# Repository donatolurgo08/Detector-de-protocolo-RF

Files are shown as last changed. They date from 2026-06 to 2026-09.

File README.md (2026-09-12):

# Detector de Protocolo RF 433MHz v1.0

Dispositivo portátil para analizar señales de radiofrecuencia a 433MHz. Permite identificar si un control remoto utiliza **código fijo** (clonable) o **rolling code** (no clonable), mostrando los resultados en pantalla OLED en tiempo real.

<p align="center">
  
</p>

---

## Índice

1. [¿Cómo funciona?](#cómo-funciona)
2. [Uso del dispositivo](#uso-del-dispositivo)
3. [Hardware](#hardware)
4. [Software](#software)
5. [Fabricación](#fabricación)
6. [Roadmap](#roadmap)

---

## ¿Cómo funciona?

El dispositivo escucha señales en la frecuencia de **433.92MHz** a través de un receptor RF. Cuando detecta una transmisión, captura el **código**, el **protocolo** y la **cantidad de bits** de cada paquete recibido.

El proceso requiere **al menos 3 pulsaciones del control a analizar** (con reintento automático hasta 5 si las muestras no coinciden por ruido). Con esas capturas compara si los datos son idénticos entre sí:

- **Código fijo:** al menos 3 paquetes iguales → el control es clonable ✅
- **Rolling code:** los paquetes cambian en cada pulsación → el control no es clonable ❌

Además verifica el **bitrate** de la señal (500–700 baud): si el control trabaja fuera de ese rango muestra `BITRATE NO SOPORTADO` y no lo cuenta como pulsación.

Toda la información se visualiza en la pantalla OLED integrada.

---

## Uso del dispositivo

1. Encendido: Deslizar el interruptor lateral. La pantalla mostrará el logo y luego la pantalla de espera.
2. Apuntar el control remoto al dispositivo y presionar **3 veces** (o mantener).
3. La pantalla irá mostrando cuántas pulsaciones fueron detectadas. Si las muestras no coinciden aparece `No coinciden, repita`: apretar 1–2 veces más.
4. Al completar las capturas, se muestra el resultado:

| Pantalla | Significado |
| --- | --- |
| **COMPATIBLE** | Código fijo — clonable |
| **NO COMPATIBLE** | Rolling code — no clonable |

Ambas pantallas muestran la frecuencia detectada, el protocolo y la cantidad de bits.

5. Reiniciar: Presionar el botón lateral hace que volver a la pantalla de espera. Útil para analizar otro control o si la detección falló.

6. Apagar: deslizar el interruptor lateral a la posición OFF.

**Autoapagado:** si pasan **2 minutos sin actividad** (ningún botón ni señal), el dispositivo entra solo en modo de reposo: la pantalla se apaga y el micro duerme. Apretar el botón lateral lo despierta y lo deja listo en la pantalla de espera.

La batería es recargable — cargala mediante el puerto correspondiente cuando sea necesario.

> ⚠️ La detección depende de la librería RCSwitch, que no cubre todos los protocolos existentes. Algunos controles pueden no ser reconocidos correctamente.

---

## Hardware

### Componentes

Ver lista completa de materiales en [`docs/materiales.txt`](docs/materiales.txt).

### Conexiones

<p align="center">
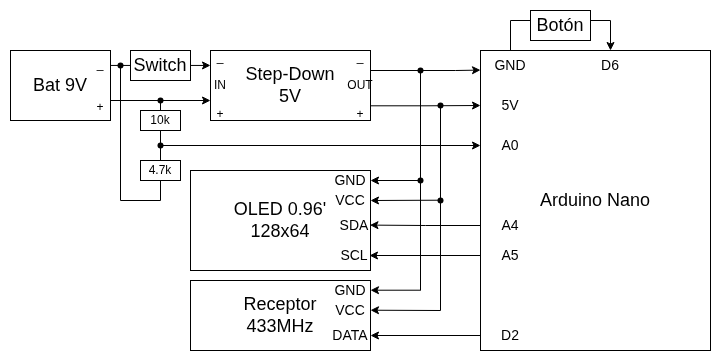
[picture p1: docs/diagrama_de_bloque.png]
  
</p>

---

## Software

[Código](https://github.com/donatolurgo08/Detector-de-protocolo-RF)

### Requisitos

El firmware está escrito en **C++ para Arduino**. Para compilarlo y flashearlo se necesita el **Arduino IDE**.

### Librerías

Instaladas desde el Library Manager del Arduino IDE:

| Librería | Autor |
| --- | --- |
| [RCSwitch](https://github.com/sui77/rc-switch) | sui77 |
| [U8g2lib](https://github.com/olikraus/u8g2) | olikraus |

### Flashear el dispositivo

1. Abrir la capeta `detector_de_protocolo_rf` con Arduino IDE
2. Bajar las librerias con el library manager
3. Seleccioná la placa **Arduino Nano** y puerto COM correspondiente.
4. Hacé clic en **Subir** (→).

---

## Fabricación

El gabinete está impreso en 3D y consta de 3 piezas:

| Pieza | Archivo |
| --- | --- |
| Carcasa principal | `3D/Modelo caja.stl` |
| Tapa | `3D/Tapa.stl` |
| Tope de pantalla  | `3D/Tapa oled.stl` |

---

## Roadmap

Esta es la **versión 1.0** del producto. Las siguientes mejoras están planificadas:

- [x] Autoapagado automático luego de 2 minutos de inactividad (sleep del microcontrolador)
- [x] Mejoras a la carcasa y diseño general
- [x] Soporte para detección de señales a **315MHz**
- [x] Diseño final en PCB dedicada para reducir costos y simplificar el ensamblado

---

_Universal Bi-Tech — Detector de Protocolo RF 433MHz_

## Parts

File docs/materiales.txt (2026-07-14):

- Arduino Nano
- Modulo receptor 433,92MHz
- Pantalla Oled 0,96” 128x64
- Bateria 9V recargable
- Modulo step down
- Switch ON/OF
- Pulsador NA
- Resistencias 10k y 4,7k
- Caja plastica
- PCB perforada

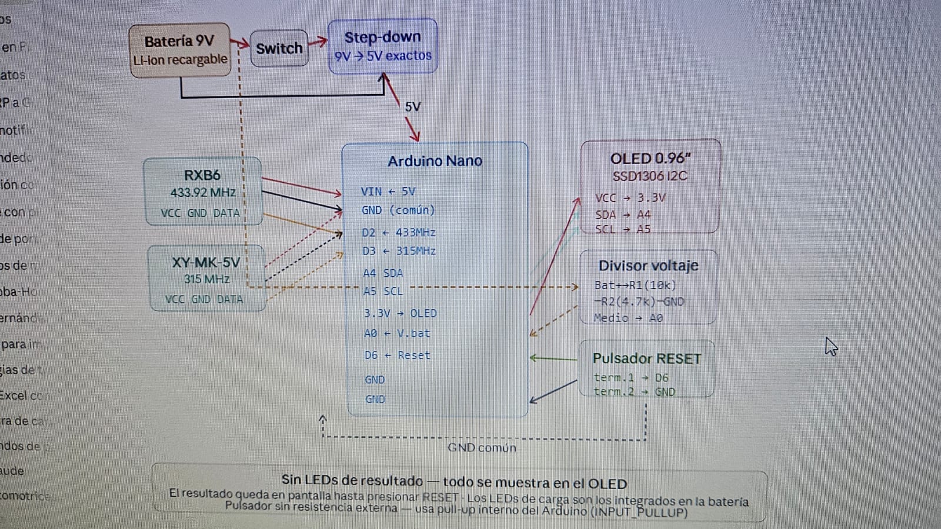
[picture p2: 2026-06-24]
docs/diagrama_componentes_original.jpeg

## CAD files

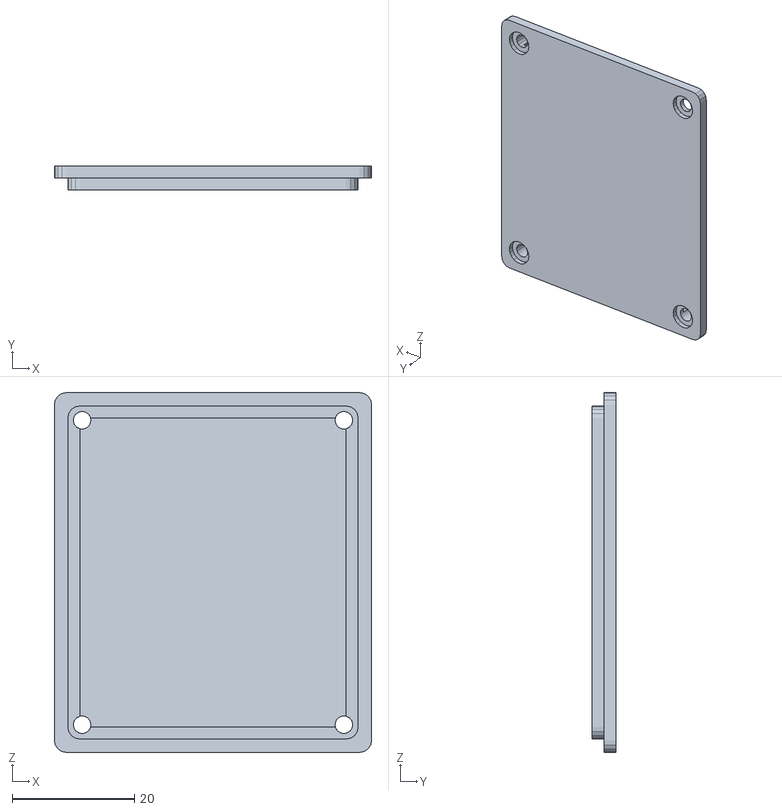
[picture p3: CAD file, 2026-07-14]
3D/Tapa.stl
52.0 x 4.00 x 59.0

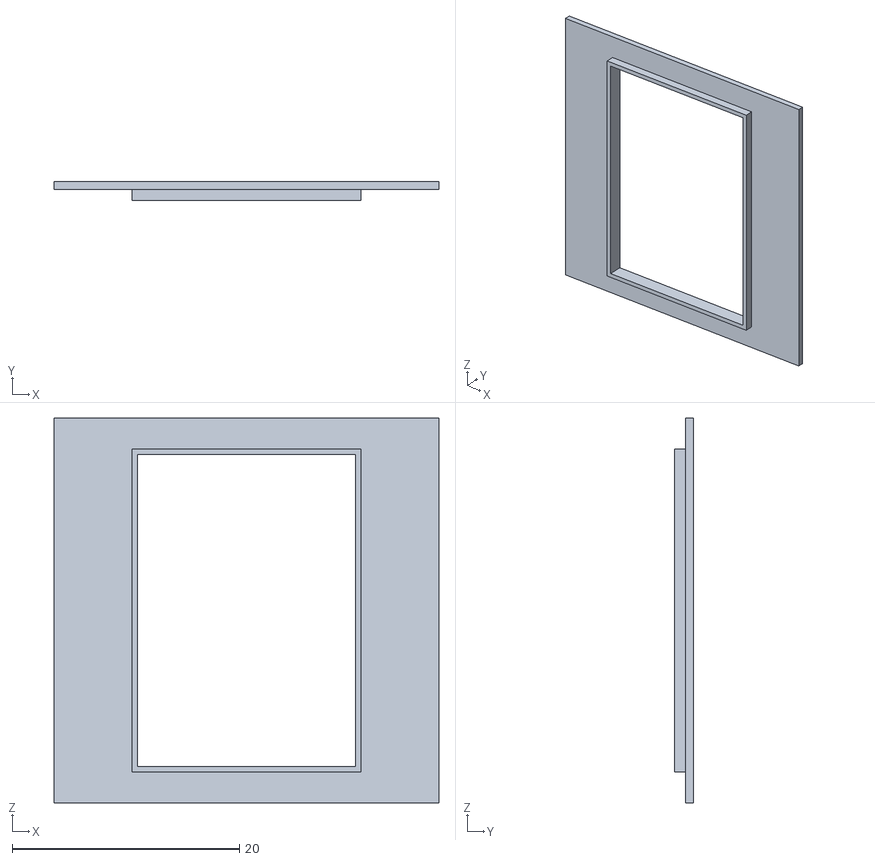
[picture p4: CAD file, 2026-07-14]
3D/Tapa oled.stl
33.9 x 1.70 x 33.9

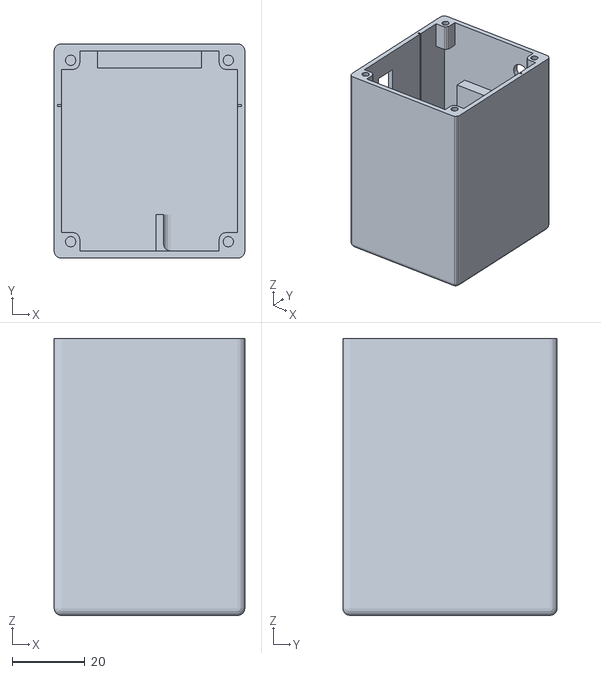
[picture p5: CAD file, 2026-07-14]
3D/Modelo caja.stl
52.5 x 59.0 x 76.2

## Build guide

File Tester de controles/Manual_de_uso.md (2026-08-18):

# Tester de controles — Manual de uso

Simulador de control remoto HT6P20 (protocolo 6 de RCSwitch, 28 bits, invertido)
para ESP32 + módulo TX 433MHz. Sirve para probar el portón y enseñarle códigos
al TXCar sin depender del control real.

## Hardware

- ESP32 DevKit.
- **Datos del módulo transmisor** → **GPIO4** (`PIN_TX`).
- **Boton**: un terminal a **GPIO18** (`PIN_BOTON`) y el otro a **GND**.
- Módulo transmisor a **433MHz**.

## Serial

- Velocidad: **9600 baud**.
- Enviar cada comando seguido de **Enter** (`\n` o `\r`).

## Comandos

| Comando | Descripción |
|---|---|
| `m` | Muestra el menú y el estado actual. |
| `a` … `g` | Selecciona el preset de código (proto 6, 28 bits). |
| `p <us>` | Fija el pulso en microsegundos (default `342`). |
| `r <n>` | Fija las repeticiones por envío (default `10`). |
| `x` | Envía 1 pulsación (n tramas seguidas). |
| `z <s>` | Transmite en continuo durante `<s>` segundos (para enseñar al TXCar). |
| Botón físico | Cada pulsación envía 1 envío (como un control real). |

### Presets

Todos son **protocolo 6, 28 bits, 433MHz**.

| Letra | Código | Pulso | ~bps | Binario | Comentario |
|---|---|---|---|---|---|
| `a` | 51252245 | 342us | ~758 | `0011000011100000110000010101` | Control real que falla en TXCar |
| `b` | 123594517 | 342us | ~758 | `0111010111011110011100010101` | Control real que funciona en TXCar |
| `c` | 58918405 | 342us | ~758 | `0011100000110000011000000101` | Sintético, muchos ceros |
| `d` | 89478485 | 342us | ~758 | `0101010101010101010101010101` | Sintético, alternado puro |
| `e` | 209517045 | 342us | ~758 | `1100011111001111100111110101` | Sintético, muchos unos |
| `f` | 99438357 | **486us** | ~534 | `0101111011010100111100010101` | 534 bps, para probar el portón |
| `g` | 136178533 | **406us** | ~638 | `1000000111011110101101100101` | 638 bps, para probar el portón |

Nota: `f` y `g` fijan también el pulso automáticamente (486us y 406us). Los
presets `a`–`e` usan el pulso actual (default 342us).

## Ejemplos de uso

- Probar el portón con el código de 534 bps:
  ```
  f
  x
  ```
- Enseñarle ese código al TXCar:
  ```
  f
  z 5
  ```
- Ver el estado actual:
  ```
  m
  ```

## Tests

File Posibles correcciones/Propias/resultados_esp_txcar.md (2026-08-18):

# Resultados: caso 51252245 (TXCar)

Prueba realizada para aislar por qué el TXCar no reproducía el control `51252245`
(clonado desde el control real) de modo que abriera el portón.

## Contexto

- Control real `51252245` (HT6P2002): el portón abre con él.
- Clonado en TXCar desde el **control real**: el TXCar NO abre el portón.
- Re-enseñado en TXCar desde el **ESP32 (señal limpia)**: patrón correcto.

## Resultados medidos (ráfagas con el detector)

| Métrica | TXCar (aprendió del control REAL) | TXCar (aprendió del ESP32) | TXCar que FUNCIONA (123594517) |
|---|---|---|---|
| tramas_total | 5 | **7** | 7 |
| Gaps | 113–114ms con **hueco de 228ms** | **111–112ms uniformes** | 112–114ms uniformes |
| sync_high | 400–500 (inestable) | **448–476 (estable)** | 476–504 |
| cero_a / cero_b | 565–597 / 979–1009 | 531–576 / 959–1001 | 527–557 / 1008–1040 |
| uno_a / uno_b | 1043–1108 / 449–508 | 1048–1092 / 440–486 | 1039–1074 / 482–516 |
| Código | 51252245 | 51252245 | 123594517 |

## Conclusión (cuál es el problema)

El problema **no es el código `51252245` ni el TXCar**: es el **proceso de
aprendizaje del TXCar cuando se le enseña desde el control real**.

El TXCar copia mal la señal RF del control original (HT6P2002), generando una
copia "sucia": pocas tramas (5), un hueco doble de 228ms entre tramas y jitter
de sincronización. Esa copia defectuosa es la que el receptor del portón rechaza.

Al enseñarle desde una señal limpia (ESP32 con RCSwitch), el TXCar reproduce
`51252245` con el mismo patrón que el clon que sí funciona: 7 tramas, gaps
parejos 111–112ms y sincronización estable.

**Solución validada:** enseñarle al TXCar desde la señal limpia
(detector → ESP32 → TXCar), no desde el control real.

## Secuencia exacta del fix

1. **Detector** en modo diagnóstico (`Tester de controles/diagnostico_detector`):
   conectado a una PC (A), monitor serial a 9600.
2. **ESP32** con el simulador (`Tester de controles/control_simulado`):
   conectado a otra PC (B), monitor serial a 9600.
3. En el ESP32: `m` para ver el menú. Elegir el código con `a..g` (presets de
   código) o ajustar pulso/repeticiones con `p <us>` / `r <n>`.
4. Verificar con `x` (1 pulsación) que el detector capta el
   `DIAGNOSTICO RAFAGA` con el código correcto y timings limpios.
5. Poner el TXCar en modo aprendizaje (según su manual).
6. En el ESP32: `z 5` — transmite el código durante 5 segundos apuntando al
   TXCar.
7. Verificar la reproducción del TXCar con el detector: debe dar ≥7 tramas y
   gaps parejos (patrón "limpio").
8. Probar contra el portón.

## Datos de referencia

- `51252245` = protocolo 6 (HT6P20B), 28 bits, pulso 342us → preset `a`.
- Presets del simulador: `a` 51252245, `b` 123594517, `c` 58918405, `d` 89478485,
  `e` 209517045, `f` 99438357 (534 bps), `g` 136178533 (638 bps).

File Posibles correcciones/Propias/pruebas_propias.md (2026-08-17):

# Pruebas propias (con el detector de protocolo RF)

Pruebas orientadas al control que falla (`51252245`, HT6P2002) y su clon en TXCar.

## A. Con el firmware actual (sin tocar código)

1. **Consistencia del clon que falla**: 5–10 pulsaciones del TXCar clonado de `51252245` → ¿siempre ~5 tramas y jitter alto? ¿O cambia según cómo se aprieta?
2. **Mantener apretado 2–3 s** en el TXCar clonado → ver `tramas_total`. Si sube de 5 a 8–10, el control manda más tramas al mantener → el problema es cantidad de repeticiones.
3. **Baseline comparativo**: hacer lo mismo con el clon que sí funciona (`123594517`) → 5 pulsaciones para tener patrón (7 tramas, gaps parejos, timings limpios).
4. **Control remoto con `pruebas/transmitter`**: el ESP32 puede regenerar exactamente el código `51252245` (proto 6, 28 bits) variando `setRepeatTransmit(4/5/7/10)` y el pulso (342 vs 539 us). Esto aísla si el detector pierde tramas por culpa del TXCar o del receptor barato. Comparar qué recibe el detector en cada configuración.

## B. Con firmware extendido

5. **Ventana de 2000 ms** → capturar la pulsación completa sin cortar la cuenta.
6. **Métricas de jitter** en el resumen (min/max/σ de símbolos 0 y 1 + tramas por pulsación) → cuantificar si el clon que falla es "sucio" de forma consistente.
7. **Prueba de re-aprendizaje**: grabar el portón usando el clon TXCar. Si abre → es tema de instalación/aprendizaje, no del clonador.

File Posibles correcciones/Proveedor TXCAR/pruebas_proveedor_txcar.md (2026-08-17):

# Pruebas para el fabricante/distribuidor del TXCar

Pruebas que debería hacer el proveedor del TXCar para determinar si el problema del control `51252245` (HT6P2002) es un error de instalación del producto o un defecto del clonador.

## Diagnóstico técnico de su producto

1. **Medir con SDR / osciloscopio** la señal emitida por el TXCar para `HT6P2002` vs `HT6P20D`:
   - Forma de onda completa (preámbulo, sync, datos, gaps entre tramas).
   - **Cantidad de repeticiones por pulsación** (nosotros medimos 5 vs 7).
   - **Jitter de cada pulso** (nosotros medimos desvíos de hasta ~30 %).
   - Frecuencia exacta (433.92 MHz o deriva).
2. **Comparar lo que el TXCar dice haber guardado vs lo que transmite** → detectar si pierde bits al aprender o al regenerar.
3. **Test de compatibilidad con HT6P2002**: probar el clon contra receptores reales de learning code para ver en cuáles falla y en cuáles no.
4. **Revisar el algoritmo de aprendizaje/reproducción**: si regenera bien `HT6P20D` pero mal `HT6P2002`, es un bug de su software (ambos son familia HT6P20, deberían tratarse igual).

## Cierre de caso (soporte)

5. **Actualización de firmware del TXCar** si es actualizable, con este caso como repro.
6. **Manual/instalación**: documentar qué encoders soporta de forma confiable y si ciertos receptores exigen re-aprender con el clon.

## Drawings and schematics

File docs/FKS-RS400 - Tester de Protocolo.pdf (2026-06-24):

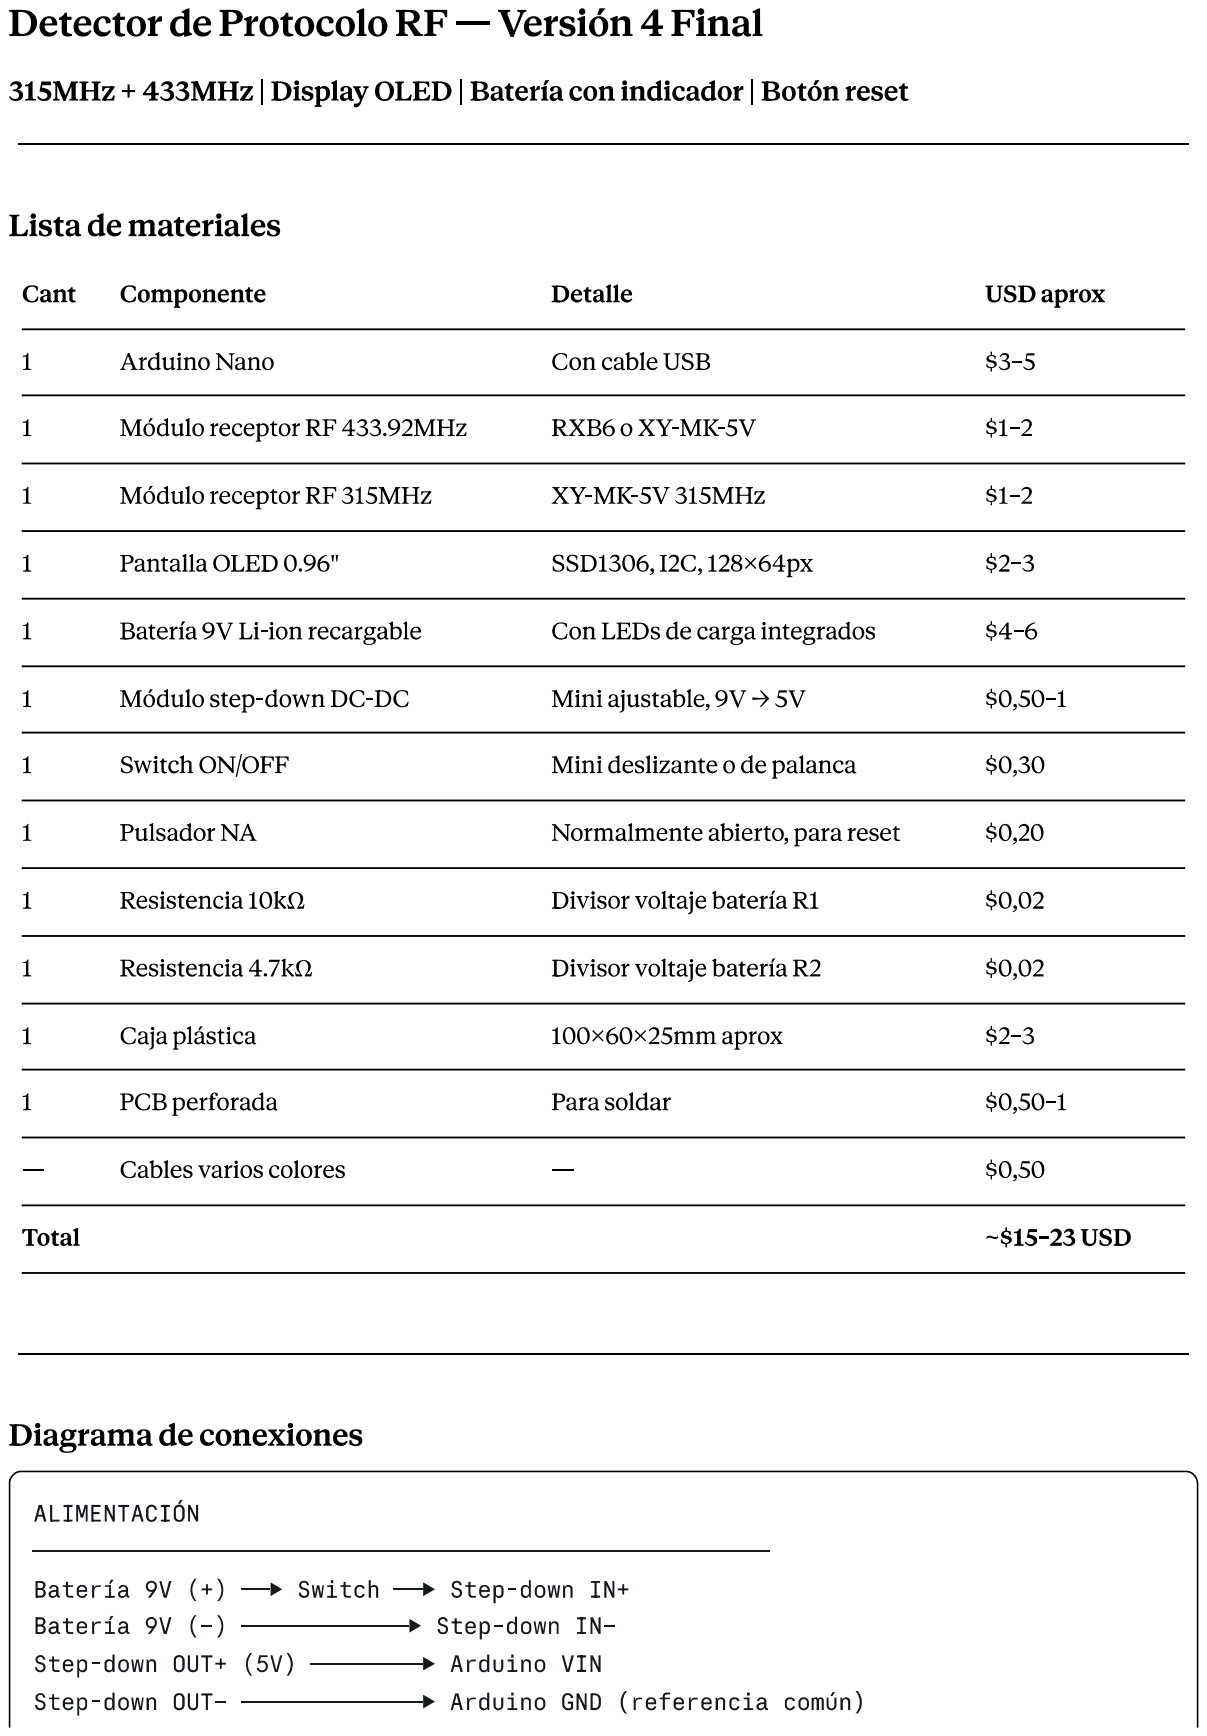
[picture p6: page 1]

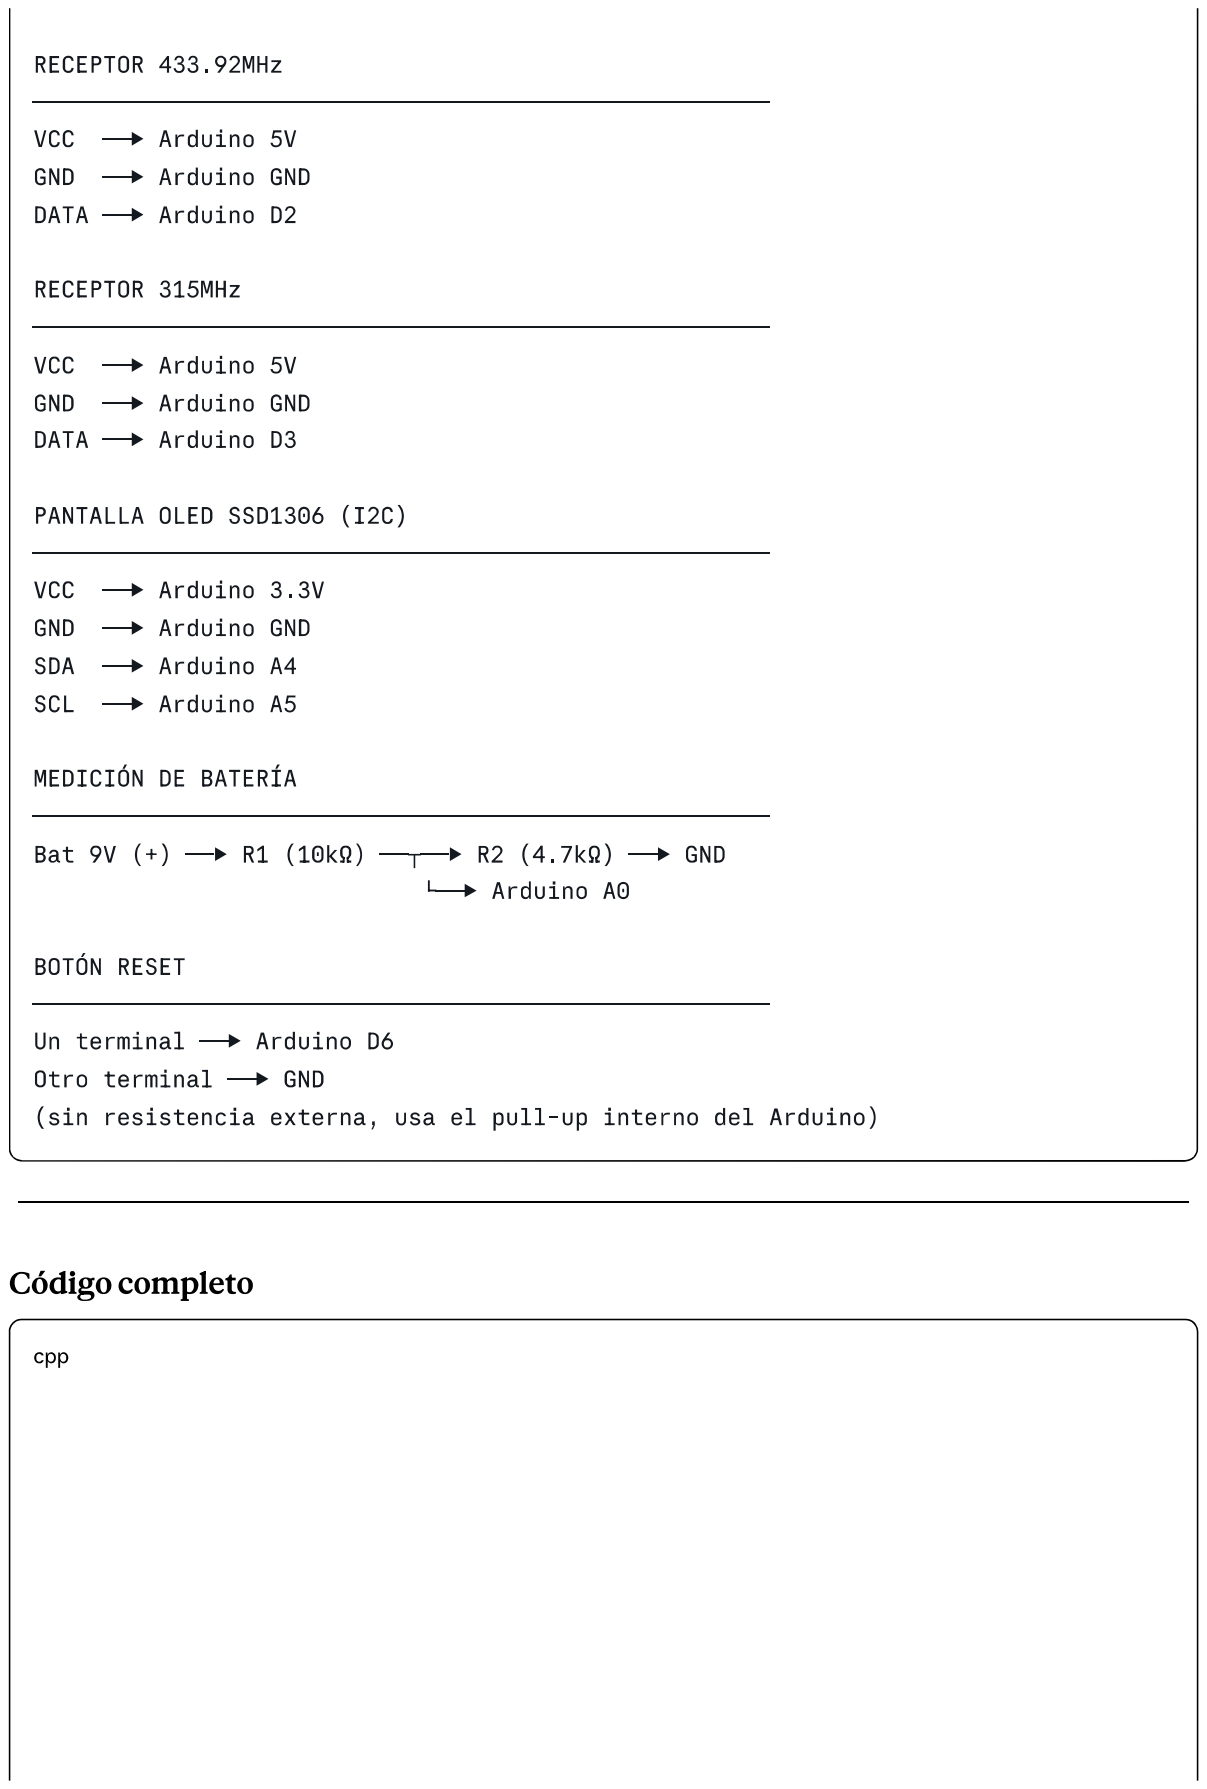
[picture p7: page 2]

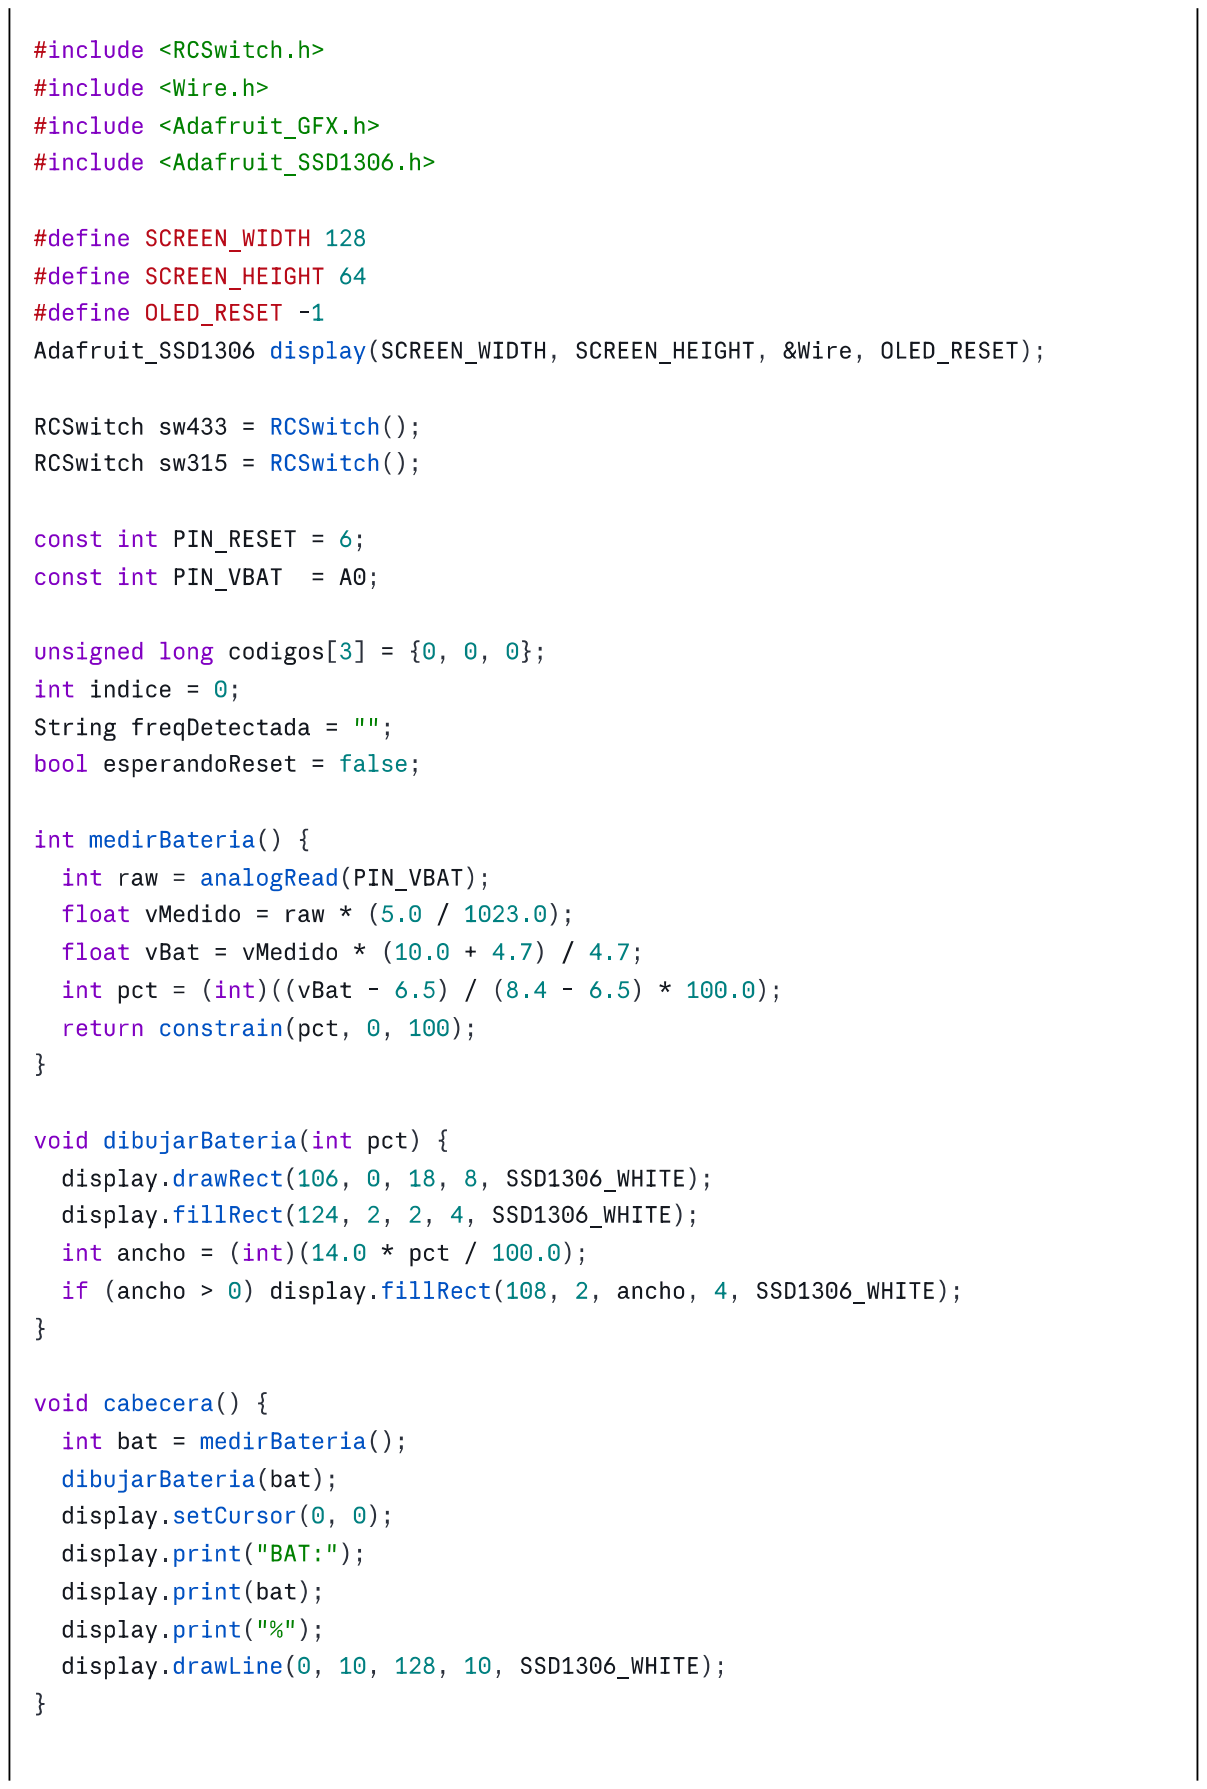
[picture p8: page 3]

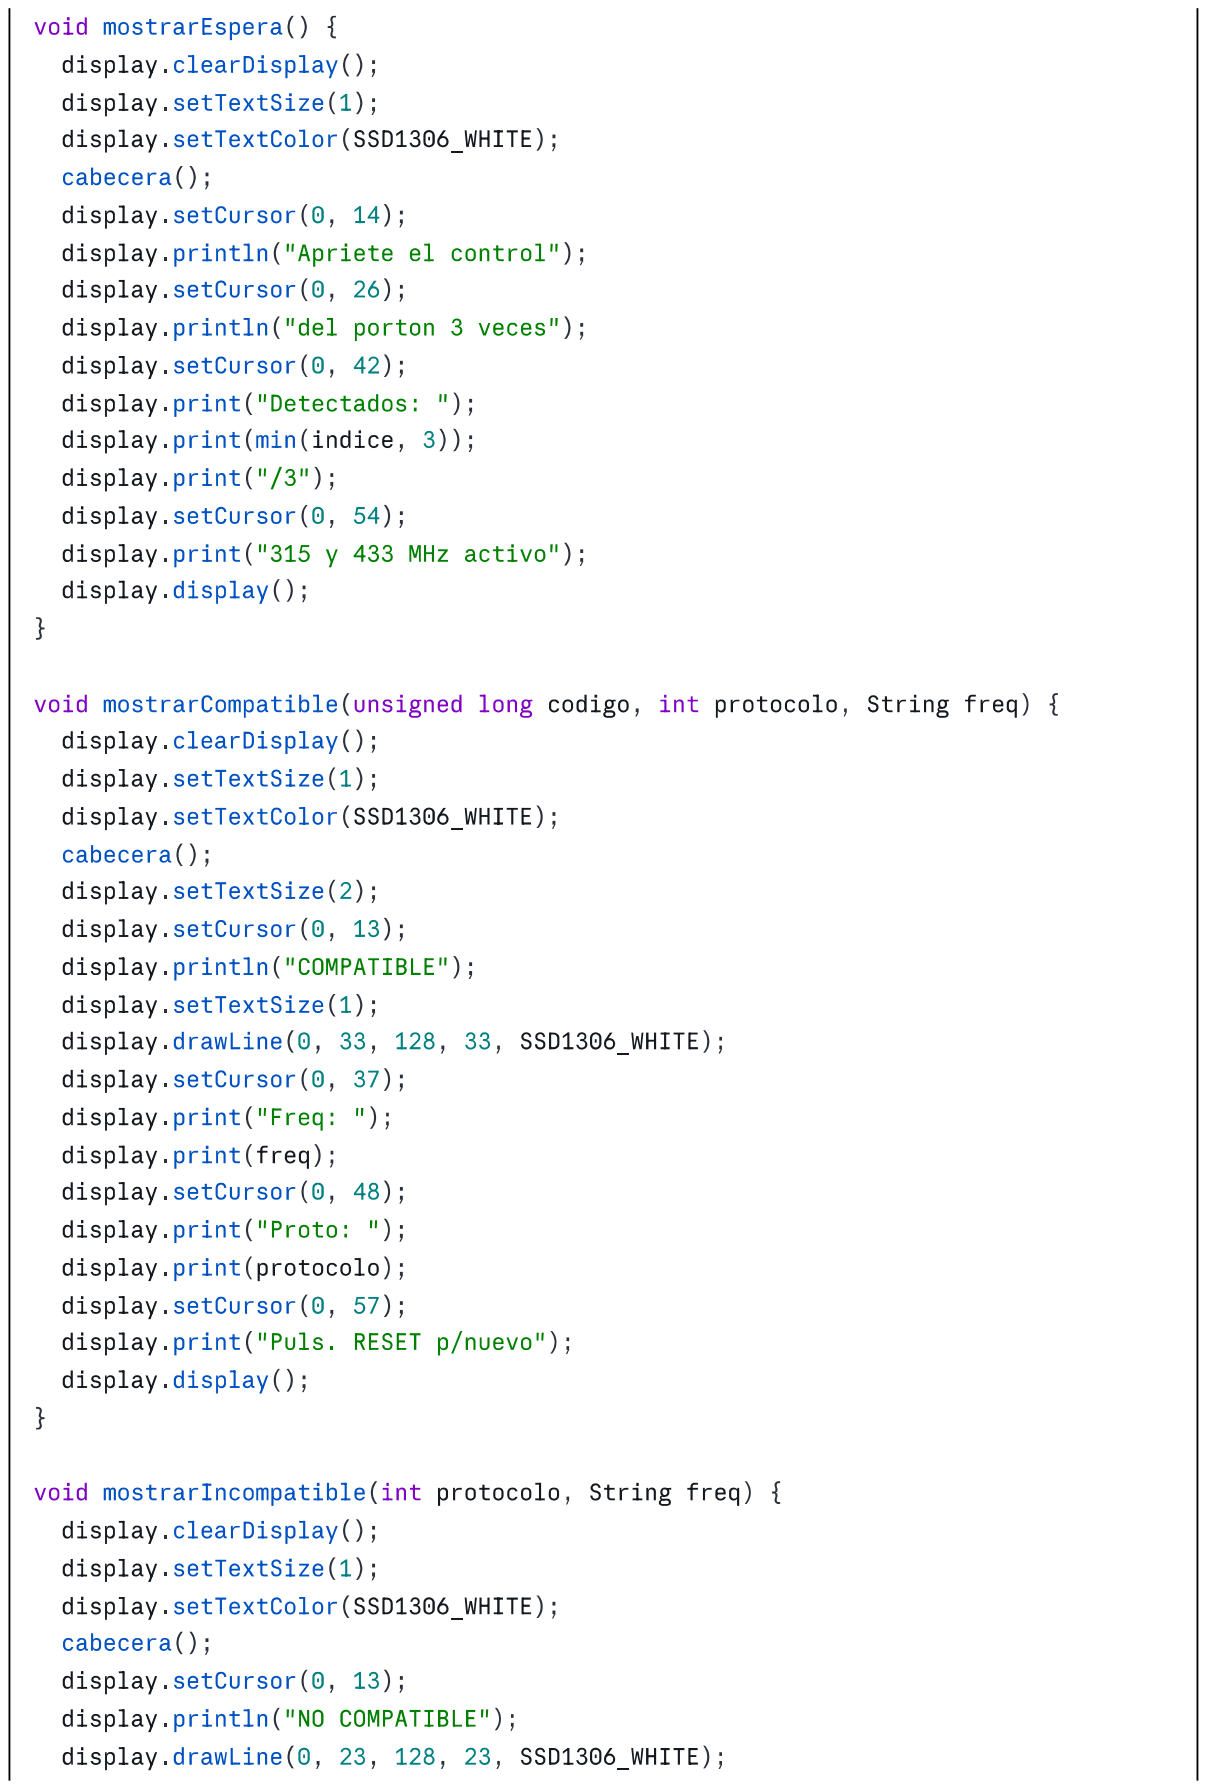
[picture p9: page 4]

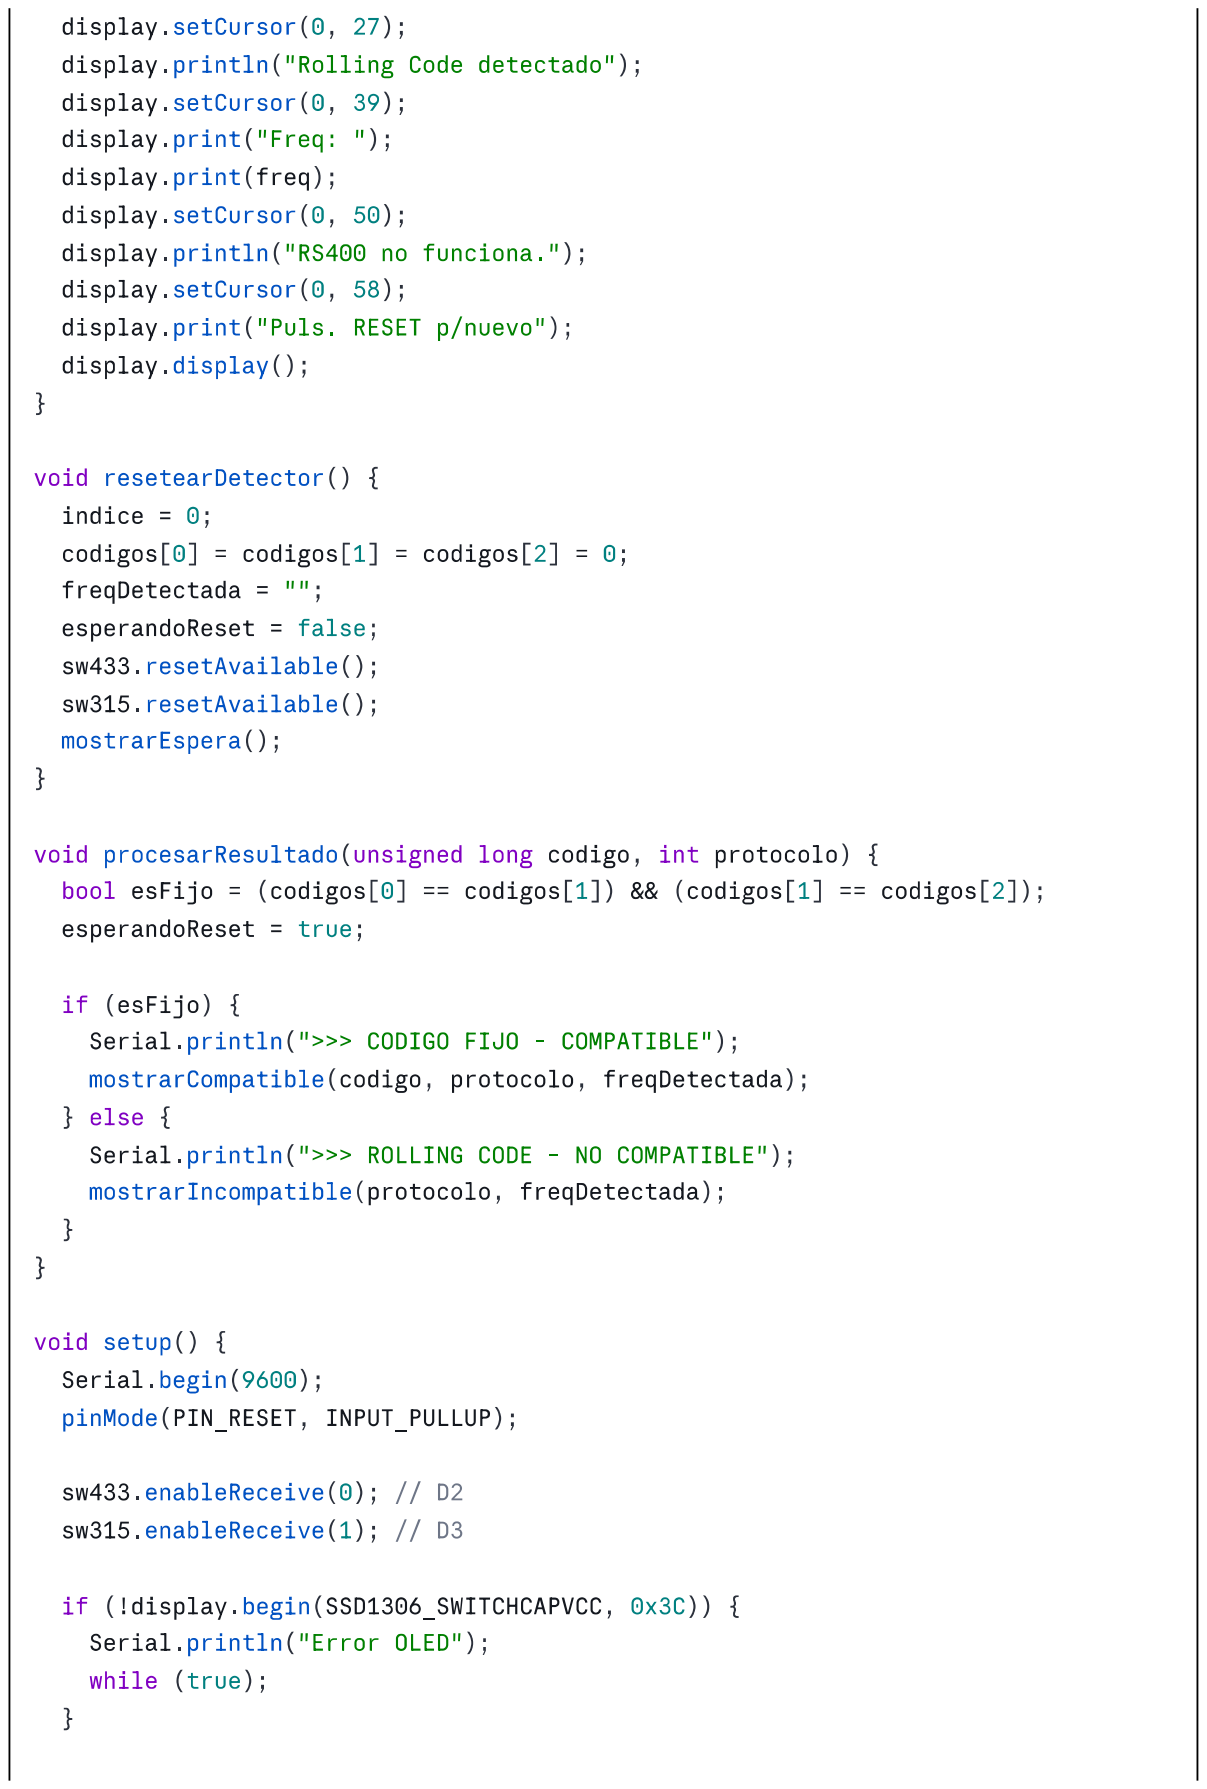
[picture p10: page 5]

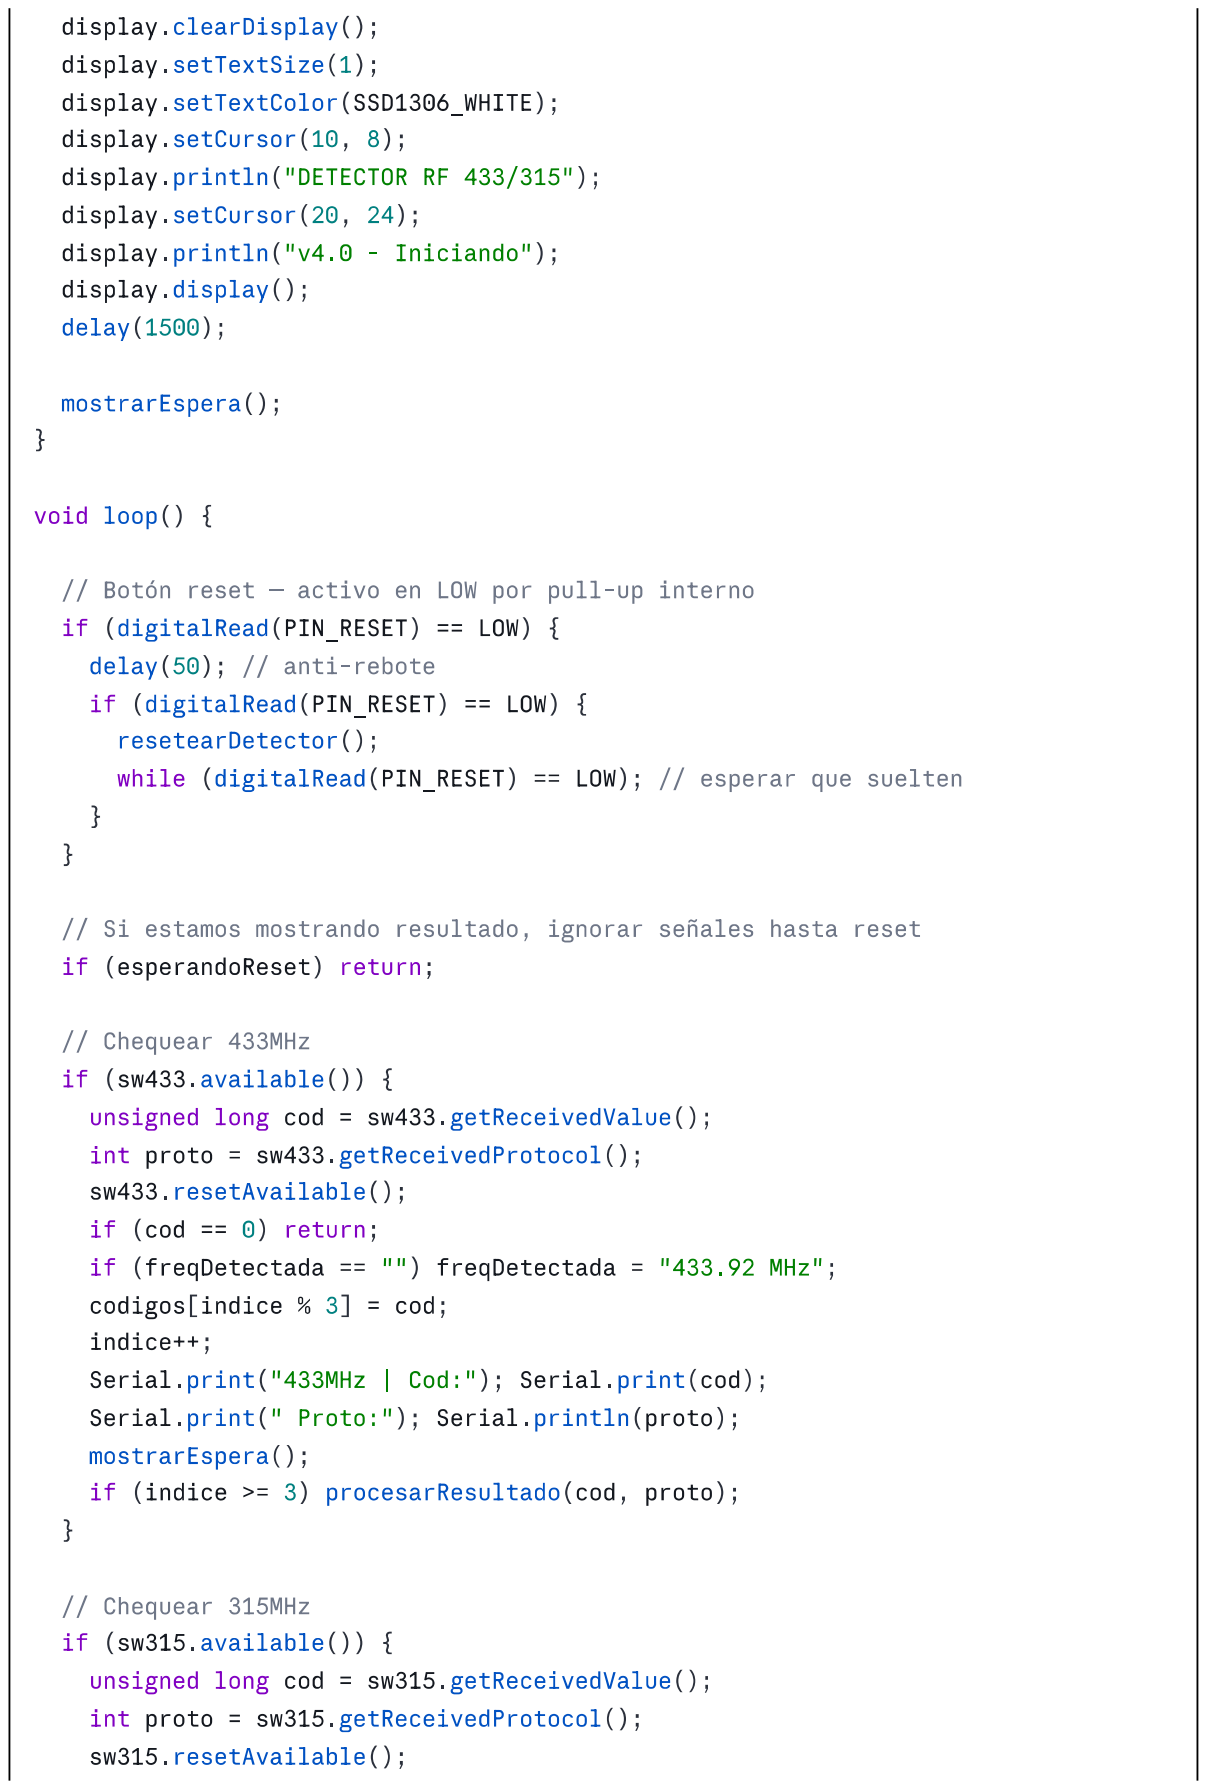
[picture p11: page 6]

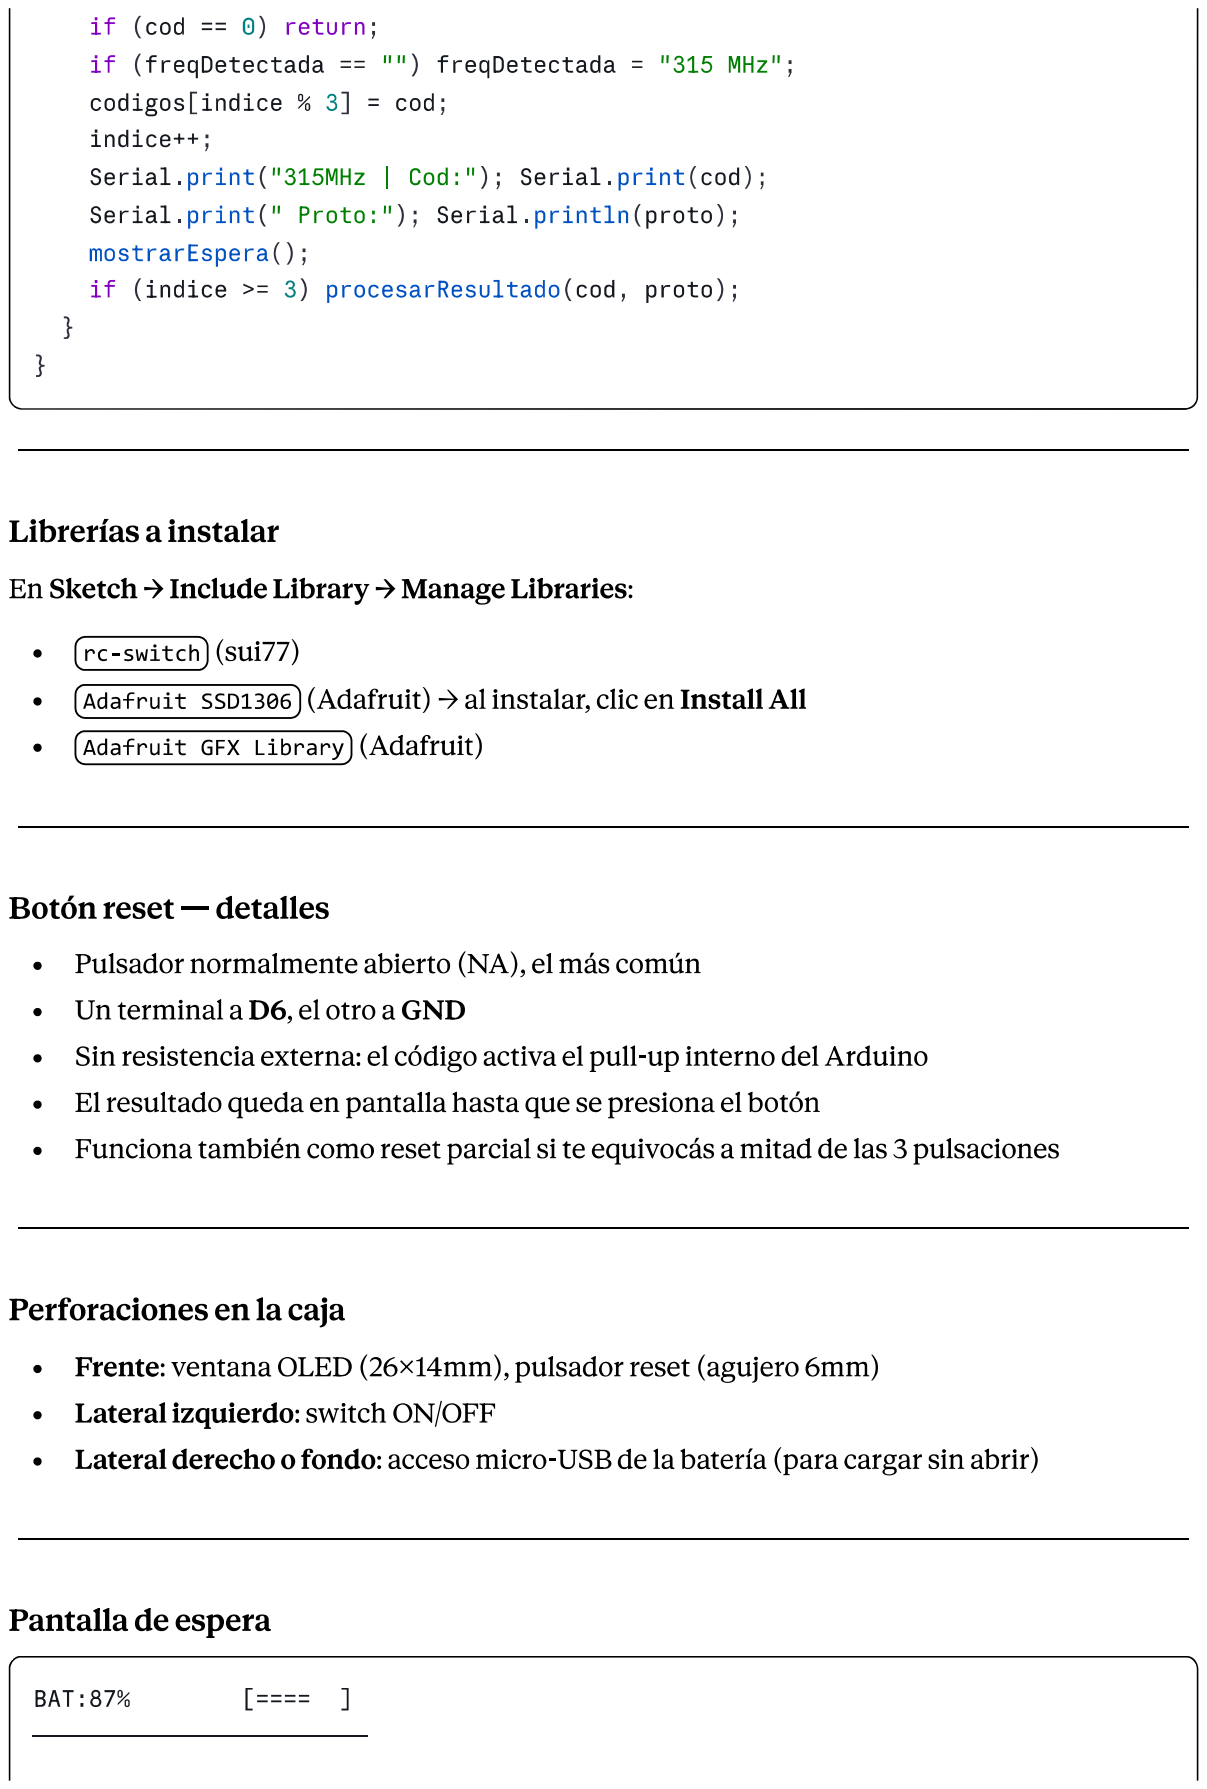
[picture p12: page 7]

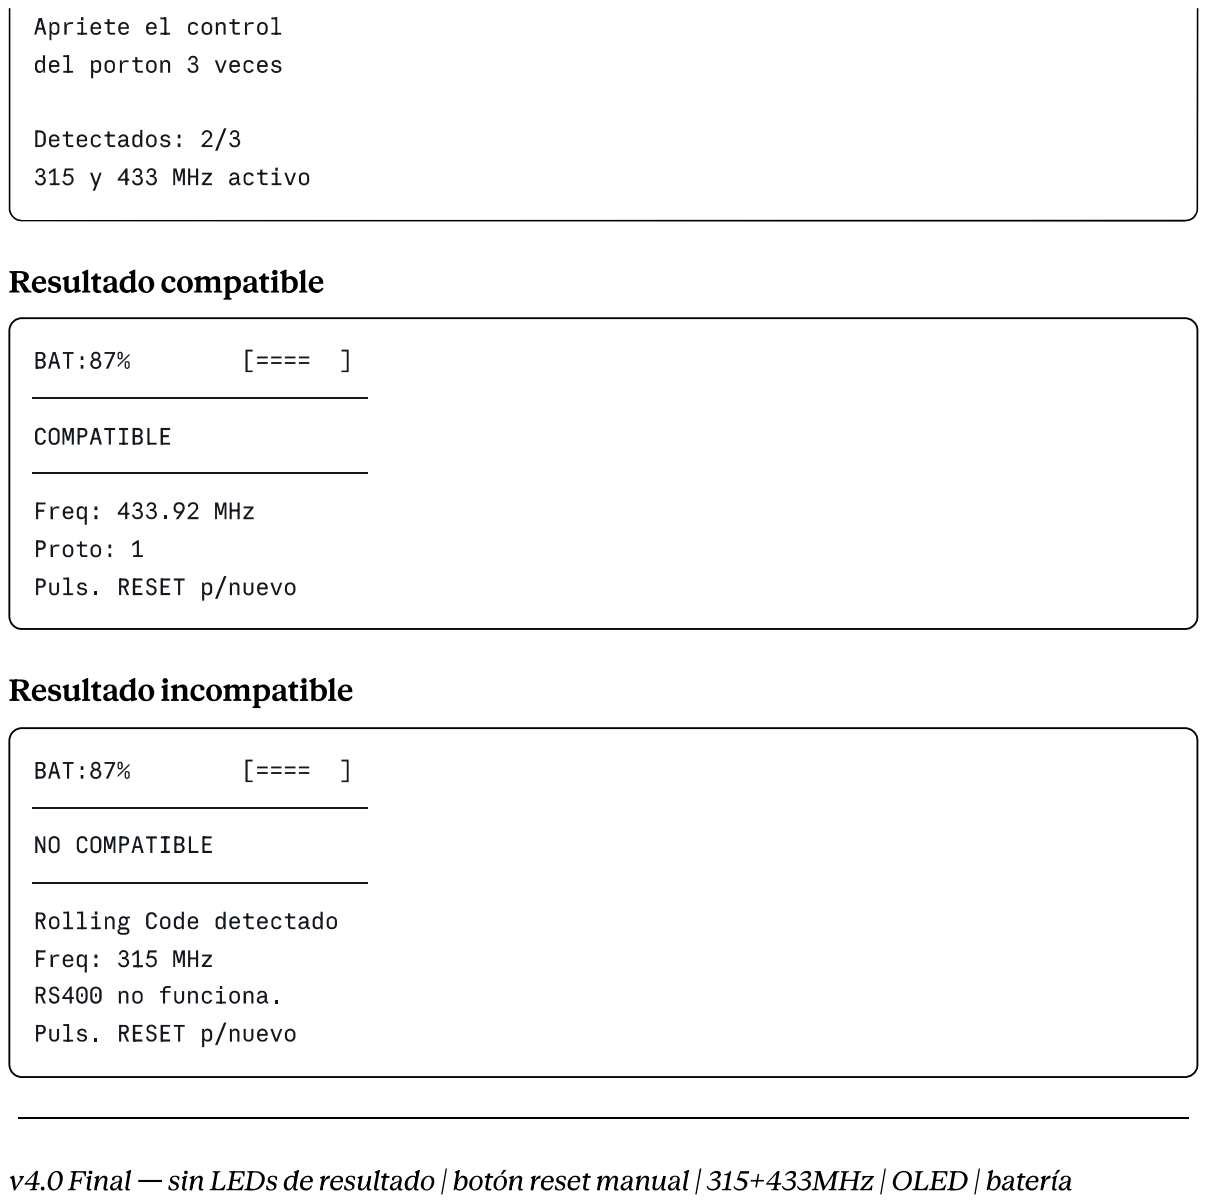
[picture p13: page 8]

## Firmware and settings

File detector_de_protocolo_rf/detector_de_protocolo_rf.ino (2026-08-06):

#include <RCSwitch.h>
#include <U8g2lib.h>
#include <Wire.h>
#include <avr/sleep.h>
#include <avr/wdt.h>
#include "logo_bitech.h"

// U8g2 en modo página de 128 bytes (vs 1024 de Adafruit)
U8G2_SSD1306_128X64_NONAME_2_HW_I2C u8g2(U8G2_R0, U8X8_PIN_NONE);

RCSwitch sw433 = RCSwitch();

const int PIN_RESET = 6;

// ---- Constantes de detección ----
const int MAX_CAPTURAS = 5;     // máximo de capturas antes de decidir
const int MIN_IGUALES = 3;      // mínimo de tramas iguales para dar COMPATIBLE
const int BAUD_MIN = 400;       // ventana de bitrate soportada (baud)
const int BAUD_MAX = 800;
const int RECEIVE_TOLERANCE = 50;  // % de tolerancia de RCSwitch (default 60)
const unsigned long TIMEOUT_SLEEP = 120000UL;  // autoapagado por inactividad (2 min)

// ---- Struct de paquete ----
struct Paquete
{
  unsigned long codigo;
  int protocolo;
  int bits;
  int pulso;
  int baud;
};

Paquete capturas[MAX_CAPTURAS];
int indice = 0;
bool esperandoReset = false;
bool reintentando = false;
unsigned long ultimaActividad = 0;

// -----------------------------------------------------------

// Factores de pulso por protocolo RCSwitch (sync, zero, one), en PROGMEM.
// La duración de la trama se deriva de estos y del pulso medido, sin depender
// del buffer crudo de timings (que el ISR sigue sobrescribiendo).
struct FactoresProto
{
  uint8_t syncH, syncL;
  uint8_t zeroH, zeroL;
  uint8_t oneH, oneL;
};

static const FactoresProto PROGMEM factoresProto[12] = {
  {  1, 31,  1,  3,  3,  1 },   // 1
  {  1, 10,  1,  2,  2,  1 },   // 2
  { 30, 71,  4, 11,  9,  6 },   // 3
  {  1,  6,  1,  3,  3,  1 },   // 4
  {  6, 14,  1,  2,  2,  1 },   // 5
  { 23,  1,  1,  2,  2,  1 },   // 6
  {  2, 62,  1,  6,  6,  1 },   // 7
  {  3,130,  7, 16,  3, 16 },   // 8
  {130,  7, 16,  7, 16,  3 },   // 9
  { 18,  1,  3,  1,  1,  3 },   // 10
  { 36,  1,  1,  2,  2,  1 },   // 11
  { 36,  1,  1,  2,  2,  1 },   // 12
};

// Bitrate (baud) promedio sobre la trama completa (sync + todos los bits).
// Determinístico: se calcula de los valores ya decodificados por RCSwitch
// (pulso, bits, código y protocolo), no del buffer crudo. Así una misma señal
// siempre da la misma baud (el buffer live variaba con el micro-timing de la
// lectura, dando dos bauds distintos para el mismo envío).
// baud = 1e6 * bits / (pulso * (suma de factores de cada bit + sync))
int calcularBaud(unsigned long codigo, int bits, int protocolo, int pulso)
{
  if (bits <= 0 || pulso <= 0 || protocolo < 1 || protocolo > 12)
    return 0;

  FactoresProto f;
  memcpy_P(&f, &factoresProto[protocolo - 1], sizeof(FactoresProto));

  unsigned long sumaFactor = f.syncH + f.syncL;   // el sync forma parte de la trama
  for (int i = bits - 1; i >= 0; i--)
  {
    if (codigo & (1UL << i))
      sumaFactor += f.oneH + f.oneL;
    else
      sumaFactor += f.zeroH + f.zeroL;
  }

  unsigned long sumaUs = (unsigned long)pulso * sumaFactor;
  if (sumaUs == 0)
    return 0;                           // evitar división por cero

  return (int)(1000000UL * bits / sumaUs);
}

// -----------------------------------------------------------

void resetearDetector()
{
  indice = 0;
  esperandoReset = false;
  reintentando = false;
  for (int i = 0; i < MAX_CAPTURAS; i++)
    capturas[i] = {0, 0, 0, 0, 0};
  sw433.resetAvailable();
  mostrarEspera();
}

// Comparación tolerante: tolera un bit de diferencia (glitches del receptor).
// - El pulso (µs) debe ser similar: mismo control => mismo ritmo de transmisión.
// - Bits iguales: el código debe coincidir.
// - Bits difieren en 1: coincide si el código es idéntico (glitch al final en
//   protocolos invertidos) o si coincide al descartar el bit espurio (codigo>>1).
bool mismaTrama(Paquete &a, Paquete &b)
{
  if (a.protocolo != b.protocolo)
    return false;

  // Pulso similar (tolerancia 20% + 40us de piso por jitter de la medición)
  long diffPulso = abs((long)a.pulso - b.pulso);
  if (diffPulso > (long)a.pulso * 20 / 100 + 40)
    return false;

  int diffBits = abs(a.bits - b.bits);
  if (diffBits > 1)
    return false;
  if (diffBits == 0)
    return a.codigo == b.codigo;
  if (a.bits > b.bits)
    return (a.codigo == b.codigo) || ((a.codigo >> 1) == b.codigo);
  return (a.codigo == b.codigo) || ((b.codigo >> 1) == a.codigo);
}

// Busca la trama que se repite al menos MIN_IGUALES veces (mayoría de votos).
bool obtenerMayoria(Paquete &ganador)
{
  for (int i = 0; i < indice; i++)
  {
    int cont = 0;
    for (int j = 0; j < indice; j++)
    {
      if (mismaTrama(capturas[i], capturas[j]))
        cont++;
    }
    if (cont >= MIN_IGUALES)
    {
      ganador = capturas[i];
      return true;
    }
  }
  return false;
}

// Compatibilidad del protocolo con el receptor RS400TX:
//   2 = confirmado, 1 = probable, 0 = no compatible
int compatibilidadProtocolo(int protocolo)
{
  switch (protocolo)
  {
    case 6:                                  // HT6P20B: confirmado
      return 2;
    case 1: case 2: case 4: case 5:          // PT2262 genérico y otros
    case 11: case 12:                        // HT12E, SM5212: probables
      return 1;
    default:                                 // 3, 7, 8, 9, 10: no
      return 0;
  }
}

void procesarResultado(Paquete &ganador, bool esFijo)
{
  esperandoReset = true;

  // Prioridad en condiciones de carrera: rolling code > bps > protocolo
  if (!esFijo)
  {
    mostrarRollingCode();
    return;
  }

  if (ganador.baud < BAUD_MIN || ganador.baud > BAUD_MAX)
  {
    mostrarNoCompatibleBps(ganador);
    return;
  }

  int compat = compatibilidadProtocolo(ganador.protocolo);
  if (compat == 2)
    mostrarCompatible(ganador);
  else if (compat == 1)
    mostrarProbCompatible(ganador);
  else
    mostrarNoCompatible(ganador);
}

// -----------------------------------------------------------
// Autoapagado por inactividad

// Interrupción de cambio de pin del botón (PD6 = PCINT22): solo se usa para
// despertar el micro desde el sleep. El debounce lo sigue haciendo el loop.
ISR(PCINT2_vect)
{
}

void irASleep()
{
  // No dormir si el botón está presionado
  if (digitalRead(PIN_RESET) == LOW)
    return;

  // Apagar la pantalla OLED
  u8g2.sleepOn();

  // Desactivar la recepción RF: durante el sleep solo despertará el botón
  sw433.disableReceive();

  // Habilitar interrupción por cambio de pin en el botón (grupo PORTD)
  PCMSK2 |= (1 << PCINT22);
  PCICR |= (1 << PCIE2);
  PCIFR |= (1 << PCIF2);   // limpiar flags pendientes

  // Apagar el ADC mientras duerme (ahorra batería)
  ADCSRA &= ~(1 << ADEN);

  // Cerrar carrera: si el botón se apretó mientras se preparaba el sleep,
  // el PCINT ya habría ocurrido y no despertaría. Mejor no dormir.
  if (digitalRead(PIN_RESET) == LOW)
  {
    ADCSRA |= (1 << ADEN);
    PCMSK2 &= ~(1 << PCINT22);
    PCICR &= ~(1 << PCIE2);
    u8g2.sleepOff();
    EIFR |= (1 << INTF0);
    sw433.enableReceive(0);
    return;
  }

  // Desactivar el watchdog durante el sleep (si no, despierta cada 8 s)
  wdt_disable();

  set_sleep_mode(SLEEP_MODE_PWR_DOWN);
  sleep_enable();
  sleep_cpu();      // queda dormido hasta que el botón genere la interrupción
  sleep_disable();

  // Despertó: reactivar watchdog y ADC
  wdt_enable(WDTO_8S);
  ADCSRA |= (1 << ADEN);

  // Limpiar interrupción del botón
  PCMSK2 &= ~(1 << PCINT22);
  PCICR &= ~(1 << PCIE2);

  // Reactivar display y recepción
  u8g2.sleepOff();
  EIFR |= (1 << INTF0);   // limpiar flag pendiente de INT0 antes de reactivar
  sw433.enableReceive(0);

  // Reiniciar a la pantalla de espera (la batería se re-mide sola en cada marco)
  ultimaActividad = millis();
  resetearDetector();
}

// -----------------------------------------------------------

void setup()
{
  Serial.begin(9600);
  pinMode(PIN_RESET, INPUT_PULLUP);

  u8g2.begin();
  u8g2.setFont(u8g2_font_6x10_tf);

  // logo
  u8g2.firstPage();
  do
  {
    u8g2.drawXBMP(0, 0, LOGO_W, LOGO_H, logo_bitech);
  } while (u8g2.nextPage());

  delay(1300);

  // titulo
  u8g2.firstPage();
  do
  {
    u8g2.setFont(u8g2_font_10x20_tf);
    u8g2.setCursor(10, 28);
    u8g2.print(F("RF ANALYZER"));
    u8g2.setFont(u8g2_font_9x15_tf);
    u8g2.setCursor(22, 52);
    u8g2.print(F("433 MHz"));
  } while (u8g2.nextPage());

  delay(1300);
  u8g2.setFont(u8g2_font_6x10_tf);
  sw433.setReceiveTolerance(RECEIVE_TOLERANCE);
  sw433.enableReceive(0);
  ultimaActividad = millis();
  mostrarEspera();

  // Watchdog: reinicia el micro si el loop se cuelga (>8 s sin wdt_reset)
  wdt_enable(WDTO_8S);
}

void loop()
{
  wdt_reset();

  // Botón reset por flanco de bajada (no bloquea el loop si queda presionado)
  static bool botonPrevio = false;
  bool botonAhora = (digitalRead(PIN_RESET) == LOW);
  if (!botonPrevio && botonAhora)
  {
    delay(50);   // debounce
    if (digitalRead(PIN_RESET) == LOW)
    {
      ultimaActividad = millis();
      resetearDetector();
    }
  }
  botonPrevio = botonAhora;

  // Autoapagado por inactividad: 2 min sin actividad -> sleep
  if (millis() - ultimaActividad > TIMEOUT_SLEEP)
  {
    irASleep();
    return;
  }

  if (esperandoReset)
    return;

  if (sw433.available())
  {
    ultimaActividad = millis();

    unsigned long cod = sw433.getReceivedValue();
    int proto = sw433.getReceivedProtocol();
    int bits = sw433.getReceivedBitlength();
    int pulso = sw433.getReceivedDelay();
    // El baud se calcula de los valores decodificados (snapshots de RCSwitch),
    // no del buffer crudo, que el ISR sigue sobrescribiendo.
    int baud = calcularBaud(cod, bits, proto, pulso);
    sw433.resetAvailable();

    if (cod == 0)
      return;

    Serial.print(F("["));
    Serial.print(indice + 1);
    Serial.print(F("] cod:"));
    Serial.print(cod);
    Serial.print(F(" proto:"));
    Serial.print(proto);
    Serial.print(F(" bits:"));
    Serial.print(bits);
    Serial.print(F(" pulso:"));
    Serial.print(pulso);
    Serial.print(F(" baud:"));
    Serial.println(baud);

    capturas[indice] = {cod, proto, bits, pulso, baud};
    indice++;

    if (indice >= MIN_IGUALES)
    {
      Paquete ganador;
      if (obtenerMayoria(ganador))
      {
        procesarResultado(ganador, true);
        return;
      }
      if (indice >= MAX_CAPTURAS)
      {
        procesarResultado(capturas[indice - 1], false);
        return;
      }
      reintentando = true;
    }

    mostrarEspera();
  }
}

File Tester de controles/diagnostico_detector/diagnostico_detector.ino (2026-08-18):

// diagnostico_detector.ino
// Detector de protocolo RF en MODO DIAGNOSTICO DE RAFAGA.
// Copia de seguridad del firmware del producto (detector_de_protocolo_rf) con
// el modo de diagnostico por Serial que imprime una rafaga completa de tramas:
//   - ventana de 700 ms desde la primera trama
//   - hasta 8 tramas guardadas (limite de SRAM del Nano)
//   - por cada trama: pulso, bps, protocolo, bits, codigo + metricas raw
//   - gap entre tramas, sync, promedios de simbolos y la primera trama cruda
//
// Sirve para comparar la senal de un control real contra la del ESP32 (Tester
// de controles) y contra lo que reproduce el TXCar.
//
// Hardware (igual que el producto):
//   Arduino Nano, RX 433MHz DATA -> D2 (INT0), boton reset -> D6 (INPUT_PULLUP)
//   OLED 128x64 por I2C (A4/A5), Serial a 9600.
//
// Uso:
//   1. Subir este sketch al Nano.
//   2. Abrir el monitor serial a 9600.
//   3. Apretar el boton (o resetear) para iniciar una captura.
//   4. Accionar el control/ESP/TXCar una vez.
//   5. Al cerrar la ventana de 700 ms imprime el resumen y queda esperando
//      reset (boton) para la proxima captura.

#include <RCSwitch.h>
#include <U8g2lib.h>
#include <Wire.h>
#include <avr/sleep.h>
#include <avr/wdt.h>
#include "logo_bitech.h"

// U8g2 en modo pagina de 128 bytes (vs 1024 de Adafruit)
U8G2_SSD1306_128X64_NONAME_2_HW_I2C u8g2(U8G2_R0, U8X8_PIN_NONE);

RCSwitch sw433 = RCSwitch();

const int PIN_RESET = 6;

// ---- Constantes de deteccion ----
const int MAX_CAPTURAS = 5;     // maximo de capturas antes de decidir
const int MIN_IGUALES = 3;      // minimo de tramas iguales para dar COMPATIBLE
const int BAUD_MIN = 400;       // ventana de bitrate soportada (baud)
const int BAUD_MAX = 800;
const int RECEIVE_TOLERANCE = 50;  // % de tolerancia de RCSwitch (default 60)
const unsigned long TIMEOUT_SLEEP = 120000UL;  // autoapagado por inactividad (2 min)
const bool MODO_DIAGNOSTICO_RAFAGA = true;     // imprime por Serial una rafaga completa
const unsigned long VENTANA_RAFAGA_MS = 700;   // tiempo de captura desde la primera trama
const int MAX_TRAMAS_RAFAGA = 8;               // limite para cuidar SRAM del Nano

// ---- Struct de paquete ----
struct Paquete
{
  unsigned long codigo;
  int protocolo;
  int bits;
  int pulso;
  int baud;
};

struct MetricasRaw
{
  unsigned int cambios;
  unsigned long duracionUs;
  unsigned int syncA;
  unsigned int syncB;
  unsigned int ceroA;
  unsigned int ceroB;
  unsigned int unoA;
  unsigned int unoB;
  uint8_t cantCero;
  uint8_t cantUno;
};

struct TramaRafaga
{
  unsigned int tMs;
  Paquete paquete;
  MetricasRaw metricas;
};

Paquete capturas[MAX_CAPTURAS];
int indice = 0;
bool esperandoReset = false;
bool reintentando = false;
unsigned long ultimaActividad = 0;
unsigned int rawDiagnostico[RCSWITCH_MAX_CHANGES];
int rawDiagnosticoCant = 0;
unsigned int rawPrimeraTrama[RCSWITCH_MAX_CHANGES];
int rawPrimeraTramaCant = 0;
TramaRafaga tramasRafaga[MAX_TRAMAS_RAFAGA];
int cantTramasRafaga = 0;
int totalTramasRafaga = 0;
bool rafagaActiva = false;
unsigned long inicioRafaga = 0;

// -----------------------------------------------------------

// Factores de pulso por protocolo RCSwitch (sync, zero, one), en PROGMEM.
// La duracion de la trama se deriva de estos y del pulso medido, sin depender
// del buffer crudo de timings (que el ISR sigue sobrescribiendo).
struct FactoresProto
{
  uint8_t syncH, syncL;
  uint8_t zeroH, zeroL;
  uint8_t oneH, oneL;
};

static const FactoresProto PROGMEM factoresProto[12] = {
  {  1, 31,  1,  3,  3,  1 },   // 1
  {  1, 10,  1,  2,  2,  1 },   // 2
  { 30, 71,  4, 11,  9,  6 },   // 3
  {  1,  6,  1,  3,  3,  1 },   // 4
  {  6, 14,  1,  2,  2,  1 },   // 5
  { 23,  1,  1,  2,  2,  1 },   // 6
  {  2, 62,  1,  6,  6,  1 },   // 7
  {  3,130,  7, 16,  3, 16 },   // 8
  {130,  7, 16,  7, 16,  3 },   // 9
  { 18,  1,  3,  1,  1,  3 },   // 10
  { 36,  1,  1,  2,  2,  1 },   // 11
  { 36,  1,  1,  2,  2,  1 },   // 12
};

// Bitrate (baud) promedio sobre la trama completa (sync + todos los bits).
// baud = 1e6 * bits / (pulso * (suma de factores de cada bit + sync))
int calcularBaud(unsigned long codigo, int bits, int protocolo, int pulso)
{
  if (bits <= 0 || pulso <= 0 || protocolo < 1 || protocolo > 12)
    return 0;

  FactoresProto f;
  memcpy_P(&f, &factoresProto[protocolo - 1], sizeof(FactoresProto));

  unsigned long sumaFactor = f.syncH + f.syncL;   // el sync forma parte de la trama
  for (int i = bits - 1; i >= 0; i--)
  {
    if (codigo & (1UL << i))
      sumaFactor += f.oneH + f.oneL;
    else
      sumaFactor += f.zeroH + f.zeroL;
  }

  unsigned long sumaUs = (unsigned long)pulso * sumaFactor;
  if (sumaUs == 0)
    return 0;                           // evitar division por cero

  return (int)(1000000UL * bits / sumaUs);
}

bool protocoloInvertido(int protocolo)
{
  return protocolo == 6 || protocolo == 9 || protocolo == 10 ||
         protocolo == 11 || protocolo == 12;
}

int cantidadRawEsperada(int bits, int protocolo)
{
  int cantidad = bits * 2 + (protocoloInvertido(protocolo) ? 2 : 1);
  if (cantidad < 0)
    return 0;
  if (cantidad > RCSWITCH_MAX_CHANGES)
    return RCSWITCH_MAX_CHANGES;
  return cantidad;
}

void copiarRawDiagnostico(int cantidad)
{
  unsigned int *raw = sw433.getReceivedRawdata();
  rawDiagnosticoCant = cantidad;
  for (int i = 0; i < rawDiagnosticoCant; i++)
    rawDiagnostico[i] = raw[i];
}

void calcularMetricasRaw(Paquete &p, MetricasRaw &m)
{
  unsigned long ceroA = 0;
  unsigned long ceroB = 0;
  unsigned long unoA = 0;
  unsigned long unoB = 0;
  int cantCero = 0;
  int cantUno = 0;
  bool invertido = protocoloInvertido(p.protocolo);
  int inicioDatos = invertido ? 2 : 1;
  unsigned long duracionTotal = 0;

  for (int i = 0; i < rawDiagnosticoCant; i++)
    duracionTotal += rawDiagnostico[i];

  for (int i = 0; i < p.bits; i++)
  {
    int pos = inicioDatos + i * 2;
    if (pos + 1 >= rawDiagnosticoCant)
      break;

    int bitPos = p.bits - 1 - i;
    bool bitUno = bitPos >= 0 && bitPos < 32 && (p.codigo & (1UL << bitPos));
    if (bitUno)
    {
      unoA += rawDiagnostico[pos];
      unoB += rawDiagnostico[pos + 1];
      cantUno++;
    }
    else
    {
      ceroA += rawDiagnostico[pos];
      ceroB += rawDiagnostico[pos + 1];
      cantCero++;
    }
  }

  m.cambios = rawDiagnosticoCant;
  m.duracionUs = duracionTotal;
  m.syncA = rawDiagnosticoCant > 0 ? rawDiagnostico[0] : 0;
  m.syncB = rawDiagnosticoCant > 1 ? rawDiagnostico[1] : 0;
  m.ceroA = cantCero > 0 ? ceroA / cantCero : 0;
  m.ceroB = cantCero > 0 ? ceroB / cantCero : 0;
  m.unoA = cantUno > 0 ? unoA / cantUno : 0;
  m.unoB = cantUno > 0 ? unoB / cantUno : 0;
  m.cantCero = cantCero;
  m.cantUno = cantUno;
}

void resetearRafaga()
{
  cantTramasRafaga = 0;
  totalTramasRafaga = 0;
  rafagaActiva = false;
  inicioRafaga = 0;
  rawPrimeraTramaCant = 0;
}
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

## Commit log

2026-06-24 archivos de programa
2026-06-24 prueba de rolling code con ESP32 y modulo transmisor
2026-06-26 Detector de protocolo (funciona)
2026-06-26 modificaciones en el codigo de RF433
2026-06-29 chore: limpieza y organizacion de archivos
2026-06-29 fix: detectar rolling code con hash y no numero de pulsos
2026-06-29 fix: errores de pulsos ignoran la trama - si pulsosOK==false limpio indice y arrays, muestro pantalla de error por feedback, vuelvo a mostrar espera
2026-07-14 chore: organizacion de carpetas
2026-07-14 feat: agregar archivos 3D
    [Modelo caja.stl, Tapa oled.stl, Tapa.stl]
2026-07-14 docs: readme con imagenes y manual de usuario
2026-07-14 fix: duracion de logo al comienzo
    [detector_de_protocolo_rf.ino]
2026-08-03 feat: bitrate detection + opencode init
    [Modelo caja.stl, Tapa oled.stl, Tapa.stl]
2026-08-03 feat: robustez del firmware (watchdog, boton por flanco no bloqueante, guard de division por cero)
2026-08-03 feat: medicion de bateria estable con compensacion de VCC y aviso de carga baja
2026-08-03 feat: discriminacion por pulso en la comparacion de tramas para evitar falsos compatibles
2026-08-06 feat: transmitter de prueba con esp32
2026-08-06 feat: tener cuenta bps para compatibilidad
2026-08-06 fix: protocolos de transmitter
    [transmitter.ino]
2026-08-06 fix: cambio de calculo bps
    - ahora usa info rc-switch y no raw data
    - se le pasa code, bits, protocolo y pulso (duracion en us de pulso)
    [detector_de_protocolo_rf.ino, pantallas.ino]
2026-08-06 refactor: archivo de bateria aparte
2026-08-17 feat: plan de pruebas para caso TXCar (propias y proveedor)
2026-08-18 feat: tester de controles (simulador HT6P20 con presets a-g)
2026-08-18 docs: manual de uso del tester de controles
2026-08-18 Rename MANUAL DE USO.md to Manual de uso.md
2026-08-18 Rename Manual de uso.md to Manual_de_uso.md
2026-08-18 feat: detector de protocolo con modo diagnostico de rafaga (proyecto aparte en Tester de controles)
2026-08-18 docs: resultados caso 51252245 - TXCar aprende mal del control real, fix ensenandole desde el ESP32
2026-09-12 Actualizacion de cambios
